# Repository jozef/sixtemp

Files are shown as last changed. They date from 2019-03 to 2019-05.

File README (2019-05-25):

NAME

    sixtemp_sensor.ino - read up to six 1-wire temperature sensors using
    Arduino and show their status using R(G)B led

SYNOPSIS

    See https://github.com/jozef/sixtemp_i2c for example and usage.

DESCRIPTION

    Arduino based sensor that can read up to six 1-wire DS18B20
    temperatures. Temperature sensors addresses are permanently stored in
    eeprom so that same positions are assigned between power-cycles. It
    provides the temperature readings via I2C interface and it also shows
    the temperature using 6xred-blue leds.

 I2C SLAVE device

    Connected to I2C, by default, responds on 0x18 address.

    First I2C master has to send one byte which is the read/write address.
    Addresses are:

        0x01        led on/off bool flag
        0x21        set led on/off flag. second byte is flag value
        0x60        read 1 byte with number of sensors
        0x61..0x66  read 14 bytes of sensor 1..6 data:
                        struct sixtemp_sensor {
                            bool has_error;
                            bool has_address;
                            int16_t tdeg;
                            char address[8];
                        };

 SERIAL INTERFACE

    Using Arduino serial port:

        $ minicom --device /dev/ttyUSB1
        eeprom magic found: 6temp 0.02

    ^^^ start-up message in case if sensors and configuration was read
    successfully from eeprom.

  help/?

    Prints version and available commands:

        > ?
        6temp 0.02
        supported commands:
          temp            - show temperatures from all sensors
          forget idx      - forget sensor on position idx
          info            - show sram usage and configuration
          set i2c [num]   - set i2c address (0x18 is default)
          tled [num]      - do led blink test num times (1 is default)
          help/?          - print this help

  info

    Prints version and debug/info:

        > info
        6temp 0.02
        sram free: 1158
        current configuration:
            i2c_addr: 0x18
            i2c_register: 0x0

  temp

    Prints all available temparature sensor readings:

        > temp
        sensor 1/6 [286164122f910528]: ERROR
        sensor 2/6 [28ff3ff6a1160322]: 22.0 C
        sensor 3/6 [286164122e7c499a]: 24.0 C
        sensor 4/6 [286164122f88f163]: 24.0 C
        sensor 5/6 [28ffa59492160558]: ERROR
        sensor 6/6 [286164122f89682a]: 24.0 C

  forget

    Forget one temperature sensor:

        > forget 1
        temp address 1 forgotten
    
        > temp
        sensor 1/6: n/a
        sensor 2/6 [28ff3ff6a1160322]: 22.0 C
        sensor 3/6 [286164122e7c499a]: 24.0 C
        sensor 4/6 [286164122f88f163]: 24.0 C
        sensor 5/6 [28ffa59492160558]: ERROR
        sensor 6/6 [286164122f89682a]: 24.0 C

  set i2c

    Change I2C client address:

        > set i2c 0x20
        setting i2c address to: 0x20
    
        > info
        6temp 0.02
        sram free: 1158
        current configuration:
            i2c_addr: 0x20
            i2c_register: 0x0
    
        > set i2c
        setting i2c address to: 0x18

  tled

    Will fade-in/out red leds and sequentially (1 to 6) blink with both
    red/blue leds to test if all are wired correctly:

        > tled 2
        testing 1/2
        fade all in/out red
        blink red
         red 1
         red 2
         red 3
         red 4
         red 5
         red 6
        LED test.
        blink blue
         blue 1
         blue 2
         blue 3
         blue 4
         blue 5
         blue 6
        testing 2/2
        ...

INSTALL

    Clone the repository folder into sketchbook/sixtemp_sensor and upload
    to Arduino.

HARDWARE

    KiCad schemas and pcb-s can be found in KiCad/ folder.

    See https://blog.kutej.net/2019/03/sixtemp for pictures of the
    hardware.

SEE ALSO

    I2C master library: https://github.com/jozef/sixtemp_i2c

TODO

        - info count&show number of errors per sensor

LICENSE

    This is free software, licensed under the MIT License.

AUTHOR

        Jozef Kutej

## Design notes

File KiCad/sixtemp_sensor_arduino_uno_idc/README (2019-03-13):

needs: https://github.com/jozef/KiCad_Arduino_Shields

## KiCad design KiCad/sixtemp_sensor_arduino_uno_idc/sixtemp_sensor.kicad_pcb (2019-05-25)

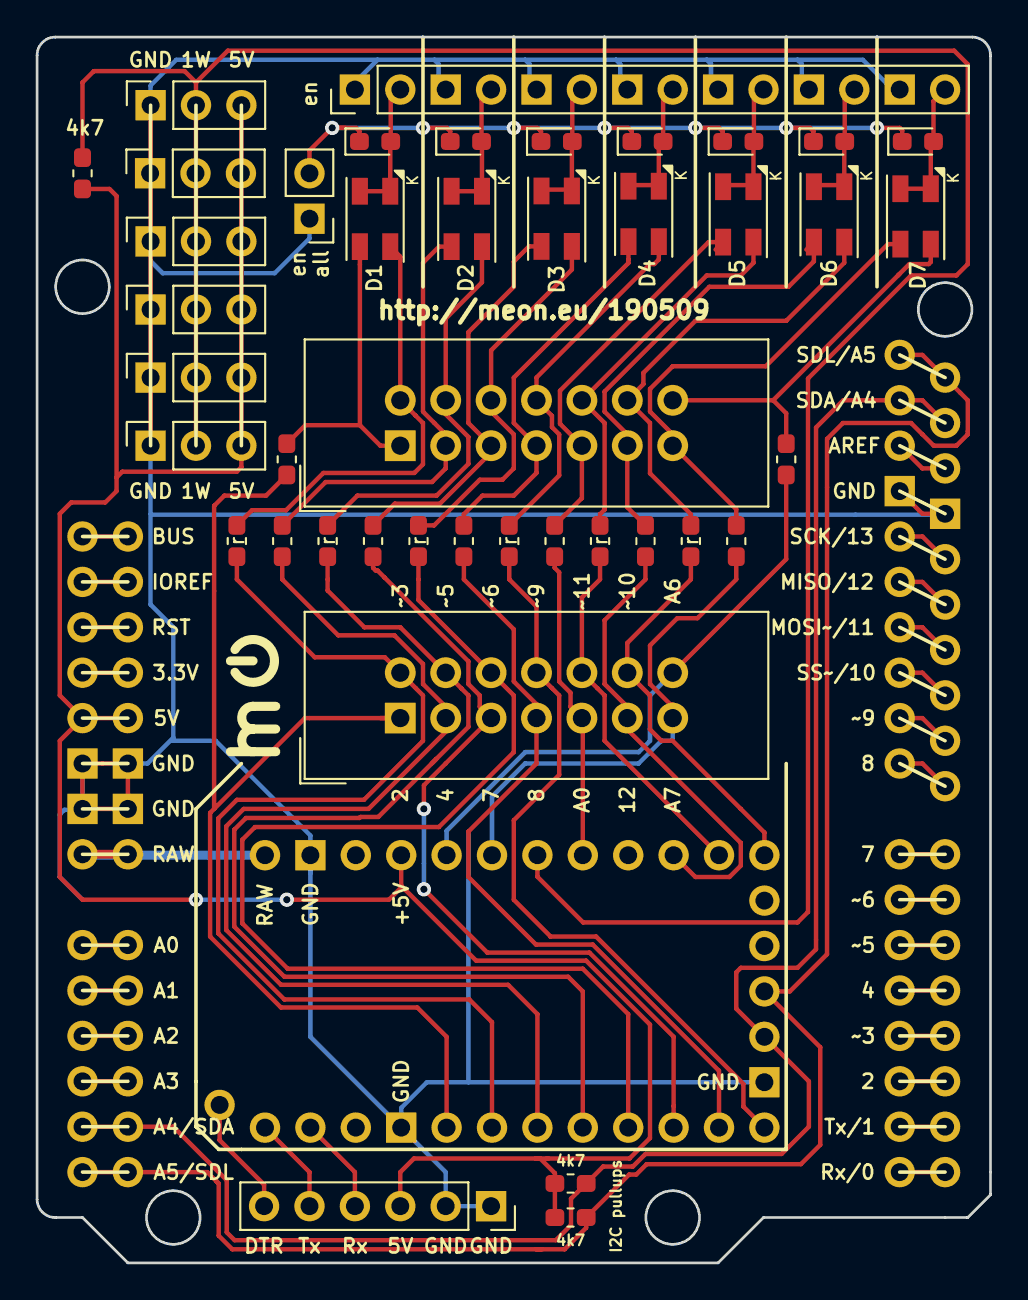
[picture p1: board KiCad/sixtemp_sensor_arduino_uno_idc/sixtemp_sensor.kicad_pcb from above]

Board: 2 copper layers, 53.3 x 68.6 mm, 44 parts (0 on the bottom side), 45 nets.

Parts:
D1, D2, D3, D4, D5, D6, D7: LED_Dual_AACC; LED_WL_SBTW_PLCC4_2.4x2.4mm_P1.7mm
D19, D29, D39, D49, D59, D69, D79: D; D_0603_1608Metric_Pad1.05x0.95mm_HandSolder
J10: debug; PinSocket_1x06_P2.54mm_Vertical
J12: Sig_conn; IDC-Header_2x07_P2.54mm_Vertical
J13: RB_Conn; IDC-Header_2x07_P2.54mm_Vertical
J31, J32, J33, J34, J35, J36: 1-Wire; PinSocket_1x03_P2.54mm_Vertical
J123456: Led_EN; PinHeader_1x14_P2.54mm_Vertical
JP99: en_all; PinHeader_1x02_P2.54mm_Vertical
R11, R12, R21, R22, R31, R32, R41, R42, R51, R52, R61, R62, R71, R72: 1k; R_0603_1608Metric_Pad1.05x0.95mm_HandSolder
R81, R82, R101: 4k7; R_0603_1608Metric_Pad1.05x0.95mm_HandSolder
U1: Arduino_Pro_Mini_12_12_5_1; Shield_Arduino_Pro_Mini_12+12+5+1_pins
U2: Arduino_Uno_Black; Arduino_Uno_Black_2rows

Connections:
1wire: J31.2, J32.2, J33.2, J34.2, J35.2, J36.2, R101.1, U1.24
10_~SS~~: J12.12, R61.2, U1.14
11_MISO~~: J12.10, R51.2, U1.15
12_MISO: J12.11, R62.2, U1.16
+5V: J10.3, J31.3, J32.3, J33.3, J34.3, J35.3, J36.3, R81.1, R82.1, R101.2, U1.4, U2.6
A0: J12.9, R52.2, U1.23
A2: J12.13, R72.2, U1.25
A3: J12.14, R71.2, U1.26
D1_Blue: D1.2, J13.1, R12.1
D1_Red: D1.1, J13.2, R11.1
D2: J12.1, R12.2, U1.32
D2_Blue: D2.2, J13.3, R22.1
D2_Red: D2.1, J13.4, R21.1
D3_Blue: D3.2, J13.5, R32.1
D3_Red: D3.1, J13.6, R31.1
D3~~: J12.2, R11.2, U1.1
D4: J12.3, R22.2, U1.2
D4_Blue: D4.2, J13.7, R42.1
D4_Red: D4.1, J13.8, R41.1
D5_Blue: D5.2, J13.9, R52.1
D5_Red: D5.1, J13.10, R51.1
D5~~: J12.4, R21.2, U1.9
D6_Blue: D6.2, J13.11, R62.1
D6_Red: D6.1, J13.12, R61.1
D6~~: J12.6, R31.2, U1.10
D7: J12.5, R32.2, U1.11
D7_Blue: D7.2, J13.13, R72.1
D7_Red: D7.1, J13.14, R71.1
D8: J12.7, R42.2, U1.12
D9~~: J12.8, R41.2, U1.13
DTR: J10.6, U1.90
EN_D1: D1.3, D1.4, D19.2, J123456.2
EN_D2: D2.3, D2.4, D29.2, J123456.4
EN_D3: D3.3, D3.4, D39.2, J123456.6
EN_D4: D4.3, D4.4, D49.2, J123456.8
EN_D5: D5.3, D5.4, D59.2, J123456.10
EN_D6: D6.3, D6.4, D69.2, J123456.12
EN_D7: D7.3, D7.4, D79.2, J123456.14
GND: J10.1, J10.2, J31.1, J32.1, J33.1, J34.1, J35.1, J36.1, J123456.1, J123456.3, J123456.5, J123456.7, J123456.9, J123456.11, J123456.13, JP99.1, U1.3, U1.5, U1.21, U2.3, U2.5, U2.21
RAW: U1.99, U2.99
Rx: J10.4, U1.30
SCL: R82.2, U1.28, U2.28
SDA: R81.2, U1.27, U2.27
Tx: J10.5, U1.31
en_all_led: D19.1, D29.1, D39.1, D49.1, D59.1, D69.1, D79.1, JP99.2

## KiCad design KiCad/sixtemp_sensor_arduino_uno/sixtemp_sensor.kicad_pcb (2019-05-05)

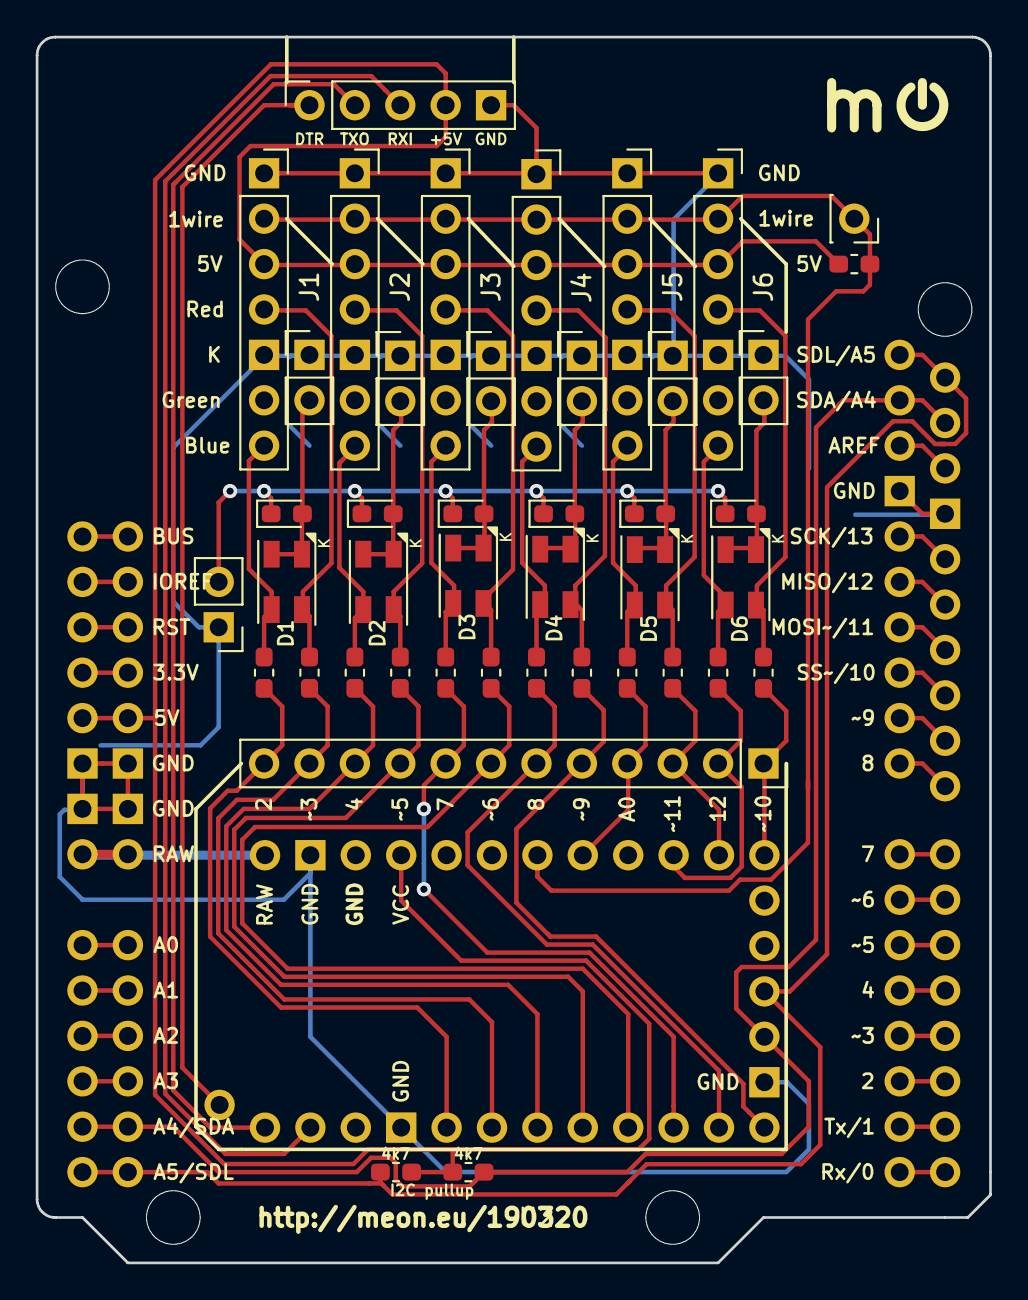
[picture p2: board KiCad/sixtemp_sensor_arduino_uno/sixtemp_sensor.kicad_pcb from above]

Board: 2 copper layers, 53.3 x 68.6 mm, 45 parts (0 on the bottom side), 40 nets.

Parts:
D1, D2, D3, D4, D5, D6: LED_Dual_AACC; LED_WL_SBTW_PLCC4_2.4x2.4mm_P1.7mm
D19, D29, D39, D49, D59, D69: D; D_0603_1608Metric_Pad1.05x0.95mm_HandSolder
J1: 1W/D_6; PinSocket_1x07_P2.54mm_Vertical
J2: 1W/D_5; PinSocket_1x07_P2.54mm_Vertical
J3: 1W/D_4; PinSocket_1x07_P2.54mm_Vertical
J4, J6: 1W/D_1; PinSocket_1x07_P2.54mm_Vertical
J5: 1W/D_2; PinSocket_1x07_P2.54mm_Vertical
J8: 1wire; PinSocket_1x01_P2.54mm_Vertical
J10: debug; PinSocket_1x05_P2.54mm_Vertical
J12: Conn_01x12_Female; PinSocket_1x12_P2.54mm_Vertical
JP1, JP2, JP3, JP4, JP5, JP6, JP99: Jumper; PinHeader_1x02_P2.54mm_Vertical
R11, R12, R21, R22, R31, R32, R41, R42, R51, R52, R61, R62: 1k; R_0603_1608Metric_Pad1.05x0.95mm_HandSolder
R81, R82, R101: 4k7; R_0603_1608Metric_Pad1.05x0.95mm_HandSolder
U1: Arduino_Pro_Mini_12_12_5_1; Shield_Arduino_Pro_Mini_12+12+5+1_pins
U2: Arduino_Uno_Black; Arduino_Uno_Black_2rows

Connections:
1wire: J1.2, J2.2, J3.2, J4.2, J5.2, J6.2, J8.1, R101.1, U1.24
10_~SS~~: J12.1, R61.2, U1.14
11_MISO~~: J12.3, R51.2, U1.15
12_MISO: J12.2, R62.2, U1.16
+5V: J1.3, J2.3, J3.3, J4.3, J5.3, J6.3, J10.4, R81.1, R82.1, R101.2, U1.4, U2.6
A0: J12.4, R52.2, U1.23
D2: J12.12, R12.2, U1.32
D3~~: J12.11, R11.2, U1.1
D4: J12.10, R22.2, U1.2
D5~~: J12.9, R21.2, U1.9
D6~~: J12.7, R31.2, U1.10
D7: J12.8, R32.2, U1.11
D8: J12.6, R42.2, U1.12
D9~~: J12.5, R41.2, U1.13
GND: J1.1, J1.5, J2.1, J2.5, J3.1, J3.5, J4.1, J4.5, J5.1, J5.5, J6.1, J6.5, J10.5, JP1.1, JP2.1, JP3.1, JP4.1, JP5.1, JP6.1, JP99.1, U1.3, U1.5, U1.21, U2.3, U2.5, U2.21
unnamed: D1.1, J1.4, R11.1
unnamed: D1.2, J1.7, R12.1
unnamed: D1.3, D1.4, D19.2, JP1.2
unnamed: D2.1, J2.4, R21.1
unnamed: D2.2, J2.7, R22.1
unnamed: D2.3, D2.4, D29.2, JP2.2
unnamed: D3.1, J3.4, R31.1
unnamed: D3.2, J3.7, R32.1
unnamed: D3.3, D3.4, D39.2, JP3.2
unnamed: D4.1, J4.4, R41.1
unnamed: D4.2, J4.7, R42.1
unnamed: D4.3, D4.4, D49.2, JP4.2
unnamed: D5.1, J5.4, R51.1
unnamed: D5.2, J5.7, R52.1
unnamed: D5.3, D5.4, D59.2, JP5.2
unnamed: D6.1, J6.4, R61.1
unnamed: D6.2, J6.7, R62.1
unnamed: D6.3, D6.4, D69.2, JP6.2
unnamed: J10.1, U1.90
unnamed: J10.2, U1.31
unnamed: J10.3, U1.30
RAW: U1.99, U2.99
SCL: R82.2, U1.28, U2.28
SDA: R81.2, U1.27, U2.27
en_all_led: D19.1, D29.1, D39.1, D49.1, D59.1, D69.1, JP99.2

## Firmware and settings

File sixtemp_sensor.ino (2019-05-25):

/*
  sixtemp_sensor.ino - read up to six 1-wire temperature sensors using Arduino
                       and show their status using R(G)B led
  (see below for documentation)
*/

#include <Arduino.h>
#include <Wire.h>
#include <OneWire.h>
#include <EEPROM.h>
#include <DallasTemperature.h>
#include <UpTime.h>             // https://github.com/jozef/Arduino-Uptime
#include "RB1WTemp.h"
#include <TextCMD.h>            // https://github.com/jozef/Arduino-TextCMD

const char MAGIC[] = "6temp 0.03";

// temperature vars
#define ONE_WIRE_BUS A1    // data one wire port A1
#define TEMPERATURE_PRECISION 12
#define MAX_SENSORS 6
const bool non_verbose = false;
const bool be_verbose = true;
const bool update_temp_leds = false;
const bool update_leds_only = true;
OneWire oneWire(ONE_WIRE_BUS);
DallasTemperature sensors(&oneWire);

#define DFT_I2C_ADDR 0x18
struct sixtemp_config {
    uint8_t i2c_addr;
    bool led_on;
    uint8_t future_conf[30];
};
uint8_t i2c_register = 0;

sixtemp_config config = {
    DFT_I2C_ADDR,    // i2c_addr
    true,            // led_on
    0,0,0,0,0,0,0,0,0,0,0,0,0,0,0,0,0,0,0,0,0,0,0,0,0,0,0,0,0,0  // place-holder for future config options
};

DeviceAddress temp_sensors[MAX_SENSORS];

#define MAX_CMD_LINE 0x1F
uint8_t current_line_end = 0;
char current_line[MAX_CMD_LINE+1];

struct ntemp_pin {
    uint8_t red;
    uint8_t blue;
};
ntemp_pin ntemp_pins[] = {
    { 3, 2 },
    { 5, 4 },
    { 6, 7 },
    { 9, 8 },
    { 11, A0 },
    { 10, 12 }
};

RB1WTemp rb1wtemps[MAX_SENSORS];

char to_send_reg0[2+sizeof(rb1wtemps[0].tdeg)+sizeof(DeviceAddress)];

#define ALARM_R_PIN A3
#define ALARM_B_PIN A2
uint8_t alarm_value = 0;

cmd_dispatch commands[] = {
    {
        "help",
        &cmd_help
    },
    {
        "?",
        &cmd_help
    },
    {
        "forget",
        &cmd_forget
    },
    {
        "cfg reset",
        &cmd_cfg_reset
    },
    {
        "temp",
        &cmd_temp
    },
    {
        "info",
        &cmd_info
    },
    {
        "set i2c",
        &cmd_set_i2c
    },
    {
        "led",
        &cmd_led
    },
    {
        "tled",
        &cmd_tled
    }
};

TextCMD cmd((sizeof(commands)/sizeof(commands[0])),commands);

const uint8_t refresh_interval = 20;
const uint8_t lookup_interval = 60;
unsigned long inactivity_ts = 0;
unsigned long next_refresh_ts = 0;
unsigned long next_lookup_ts = 0;

void setup () {
    for (uint8_t i = 0; i < MAX_SENSORS; i++) {
        rb1wtemps[i].init(ntemp_pins[i].red, ntemp_pins[i].blue,sensors);
    }

    pinMode(ALARM_R_PIN, OUTPUT);
    pinMode(ALARM_B_PIN, OUTPUT);

    Serial.begin(9600);
    while (Serial.available()) { Serial.read(); }

    char magic[strlen(MAGIC)];
    for (uint8_t i=0; i<strlen(MAGIC); i++) {
        magic[i] = EEPROM.read(i);
    }

    if (memcmp(MAGIC,magic,strlen(MAGIC)) == 0) {
        Serial.print(F("eeprom magic found: "));
        Serial.println(MAGIC);

        // read config
        for (uint8_t i = 0; i < sizeof(config); i++) {
            *((char*)&config+i) = EEPROM.read(strlen(MAGIC)+i);
        }
        // read sensors addresses
        for (uint8_t i = 0; i < MAX_SENSORS; i++) {
            uint8_t base = strlen(MAGIC)+sizeof(config)+(1+sizeof(DeviceAddress))*i;
            rb1wtemps[i].has_address = EEPROM.read(base);
            for (uint8_t si = 0; si < sizeof(DeviceAddress); si++) {
                rb1wtemps[i].address[si] = EEPROM.read(base+1+si);
            }
        }
    }
    else {
        Serial.println(F("eeprom magic missmatch, doing init"));
        // after magic, there is MAX_SENSORS of bool has_address and DeviceAddress
        // write magic
        for (uint8_t i=0; i<strlen(MAGIC); i++) {
            EEPROM.write(i,MAGIC[i]);
        }
        // write config
        for (uint8_t i = 0; i < sizeof(config); i++) {
            EEPROM.write(strlen(MAGIC)+i, *((char*)&config+i));
        }
        // zero out the rest
        for (uint8_t i=(strlen(MAGIC)+sizeof(config)); i<(strlen(MAGIC)+sizeof(config)+MAX_SENSORS+MAX_SENSORS*sizeof(DeviceAddress)); i++) {
            EEPROM.write(i,0);
        }
    }
    Serial.print(F("> "));

    Wire.begin(config.i2c_addr);
    Wire.onRequest(i2c_request);
    Wire.onReceive(i2c_receive);
}

uint8_t blink_idx = 0;
uint8_t blink_value = 1;

unsigned long tick = 0;

void loop () {
    unsigned long cur_uptime = uptime();

    // blink alarm on error
    if (no_reading_errors()) {
        digitalWrite(ALARM_R_PIN, 0);
        digitalWrite(ALARM_B_PIN, 0);
    }
    else {
        digitalWrite(ALARM_R_PIN, (alarm_value ? 1 : 0));
        digitalWrite(ALARM_B_PIN, (alarm_value ? 1 : 0));
        alarm_value = !alarm_value;
        update_temperatures(non_verbose, update_leds_only);
    }

    // re-read sensor addresses every minute
    if (next_lookup_ts < cur_uptime) {
        next_lookup_ts += lookup_interval;
        if (inactivity_ts < cur_uptime) {
            refresh_one_wire();
        }
    }
    if (next_refresh_ts < cur_uptime) {
        next_refresh_ts += refresh_interval;
        if (inactivity_ts < cur_uptime) {
            update_temperatures(non_verbose, update_temp_leds);
        }
    }

    if (inactivity_ts < cur_uptime) {
        delay(250);
    }

    while (Serial.available()) {
        static char prev_ch = 0;
        inactivity_ts = cur_uptime + 10;
        char ch = Serial.read();
        if (ch == '\b') {
            if (current_line_end) {
                Serial.print(F("\b \b"));
                current_line_end--;
                current_line[current_line_end] = '\0';
            }
        }
        else if ((ch == '\n') || (ch == '\r')) {
            if (ch == '\n' && (prev_ch == '\r')) {
                break;
            }
            Serial.println();
            if (current_line_end != 0) {
                int8_t cmd_ret = cmd.do_dispatch(current_line);
                switch (cmd_ret) {
                    case -1: Serial.println(F("unknown command or syntax error. send '?' for help")); break;
                }
                Serial.println();
            }
            Serial.print(F("> "));
            current_line[0] = '\0';
            current_line_end = 0;
        }
        else {
            if (current_line_end < MAX_CMD_LINE) {
                current_line[current_line_end++] = ch;
                current_line[current_line_end] = '\0';
                Serial.print(ch);
            }
        }
        prev_ch = ch;
    }
}

void update_temperatures(bool verbose, bool leds_only) {
    for (uint8_t i = 0; i < MAX_SENSORS; i++) {
        if (verbose) {
            Serial.print('.');
        }
        rb1wtemps[i].led_on = config.led_on;
        if (leds_only) {
            rb1wtemps[i].update_led_color(uptime());
        }
        else {
            rb1wtemps[i].refresh(uptime());
        }
    }
    if (verbose) {
        Serial.println();
    }
}

bool no_reading_errors() {
    bool one_plus_sensors = false;
    for (uint8_t i = 0; i < MAX_SENSORS; i++) {
        if (rb1wtemps[i].has_error) {
            return false;
        }
        if (rb1wtemps[i].has_address) {
            one_plus_sensors = true;
        }
    }
    if (one_plus_sensors) {
        return true;
    }
    return false;
}

void do_test_led() {
    for (uint8_t i = 0; i < MAX_SENSORS; i++) {
        rb1wtemps[i].set_red(0);
        rb1wtemps[i].set_blue(false);
    }
    digitalWrite(ALARM_R_PIN, false);
    digitalWrite(ALARM_B_PIN, false);

    Serial.println(F("fade all in/out red"));
    for (int r = 0; r < 255; r = r + 8) {
        for (uint8_t i = 0; i < MAX_SENSORS; i++) {
            rb1wtemps[i].set_red(r);
        }
        delay(30);
    }
    delay(500);
    for (int r = 255; r > 16; r = r - 8) {
        for (uint8_t i = 0; i < MAX_SENSORS; i++) {
            rb1wtemps[i].set_red(r);
        }
        delay(30);
    }
    delay(500);

    Serial.println(F("blink red"));
    for (uint8_t i = 0; i < MAX_SENSORS; i++) {
        rb1wtemps[i].set_red(255);
        Serial.print(F(" red "));
        Serial.println(i+1);
        delay(500);
        rb1wtemps[i].set_red(false);
        delay(100);
    }
    digitalWrite(ALARM_R_PIN, true);
    Serial.println(F(" red alarm"));
    delay(500);
    digitalWrite(ALARM_R_PIN, false);
    delay(500);

    Serial.println(F("LED test."));
    Serial.println(F("blink blue"));
    for (uint8_t i = 0; i < MAX_SENSORS; i++) {
        rb1wtemps[i].set_blue(true);
        Serial.print(F(" blue "));
        Serial.println(i+1);
        delay(500);
        rb1wtemps[i].set_blue(false);
        delay(100);
    }
    digitalWrite(ALARM_B_PIN, true);
    Serial.println(F(" blue alarm"));
    delay(500);
    digitalWrite(ALARM_B_PIN, false);
    delay(500);
}

void refresh_one_wire() {
    sensors.begin();
    uint8_t temp_sensors_count = sensors.getDeviceCount();
    for (uint8_t i = 0;i<temp_sensors_count;i++) {
        DeviceAddress found_sensor;
        sensors.getAddress(found_sensor,i);

        // check for known sensors and free sensor slots
        int sensor_idx = -1;
        int free_slot_idx = -1;
        for (uint8_t known_i = 0; known_i < MAX_SENSORS; known_i++) {
            if (rb1wtemps[known_i].has_address) {
                if (memcmp(rb1wtemps[known_i].address, found_sensor, sizeof(DeviceAddress)) == 0) {
                    sensor_idx = known_i;
                    break;
                }
            }
            else if (free_slot_idx == -1) {
                free_slot_idx = known_i;
            }
        }

        // save and use new found sensor
        if ((sensor_idx == -1) && (free_slot_idx != -1)) {
            Serial.print(F("new sensor found, storing at: "));
            Serial.println(free_slot_idx+1);
            Serial.println(F("> "));
            rb1wtemps[free_slot_idx].set_address(found_sensor);
            uint8_t base = strlen(MAGIC)+sizeof(config)+(1+sizeof(DeviceAddress))*free_slot_idx;
            EEPROM.write(base, 1);
            for (uint8_t si = 0; si < sizeof(DeviceAddress); si++) {
                EEPROM.write(base+si+1, rb1wtemps[free_slot_idx].address[si]);
            }
        }
    }
}

String uint8_tToString (uint8_t num) {
    if (num < 16) {
        return String("0"+String(num, HEX));
    }
    else {
        return String(num, HEX);
    }
}

int8_t cmd_forget(uint8_t argc, const char* argv[]) {
    if (argc < 2) {
        return -1;
    }
    uint8_t idx = String(argv[1]).toInt();
    if (!idx || (idx > MAX_SENSORS)) {
        Serial.print(F("failed, max sensors count is "));
        Serial.println(MAX_SENSORS);
        return 1;
    }
    rb1wtemps[idx-1].reset_address();
    uint8_t base = strlen(MAGIC)+sizeof(config)+(1+sizeof(DeviceAddress))*(idx-1);
    EEPROM.write(base, 0);
    Serial.print(F("temp address "));
    Serial.print(idx);
    Serial.println(F(" forgotten"));
    return 0;
}

int8_t cmd_tled(uint8_t argc, const char* argv[]) {
    uint8_t loops = 1;
    if (argc > 1) {
        loops = String(argv[1]).toInt();
    }
    for (uint8_t i=1; i <= loops; i++) {
        Serial.print(F("testing "));
        Serial.print(i);
        Serial.print(F("/"));
        Serial.println(loops);
        do_test_led();
    }
    return 0;
}

int8_t cmd_led(uint8_t argc, const char* argv[]) {
    if (argc < 2) {
        return -1;
    }
    if (strcmp(argv[1],"on")) {
        config.led_on = false;
    }
    else if (strcmp(argv[1],"off")) {
        config.led_on = true;
    }

    uint8_t base = strlen(MAGIC)+1;
    if (EEPROM.read(base) != config.led_on) {
        EEPROM.write(base, config.led_on);
        Serial.print(F("led set to "));
        if (config.led_on) {
            Serial.println(F("on"));
        }
        else {
            Serial.println(F("off"));
        }
    }
    return 0;
}

int8_t cmd_help(uint8_t argc, const char* argv[]) {
    Serial.println(MAGIC);
    Serial.println(F("supported commands:"));
    Serial.println(F("  temp            - show temperatures from all sensors"));
    Serial.println(F("  forget idx      - forget sensor on position idx"));
    Serial.println(F("  led on/off      - turn all led temperature indication on or off"));
    Serial.println(F("  info            - show sram usage and configuration"));
    Serial.println(F("  set i2c [num]   - set i2c address (0x18 is default)"));
    Serial.println(F("  tled [num]      - do led blink test num times (1 is default)"));
    Serial.println(F("  cfg reset       - factory reset configuration"));
    Serial.println(F("  help/?          - print this help"));
    return 0;
}

int8_t cmd_temp(uint8_t argc, const char* argv[]) {
    refresh_one_wire();
    update_temperatures(be_verbose, update_temp_leds);
    for (uint8_t i = 0; i < MAX_SENSORS; i++) {
        Serial.print(F("sensor "));
        Serial.print(i+1);
        Serial.print(F("/"));
        Serial.print(MAX_SENSORS);
        if (rb1wtemps[i].has_address) {
            Serial.print(F(" ["));
            for (uint8_t i2 = 0;i2<8;i2++) {
                Serial.print(uint8_tToString(rb1wtemps[i].address[i2]));
            }
            Serial.print(F("]: "));
            if (rb1wtemps[i].has_error) {
                Serial.println(F("ERROR"));
            }
            else {
                Serial.print(rb1wtemps[i].tdeg/10);
                Serial.print(F("."));
                Serial.print(abs(rb1wtemps[i].tdeg % 10));
                Serial.print(F(" "));
                Serial.println(F("C"));
            }
        }
        else {
            Serial.println(F(": n/a"));
        }
    }
    return 0;
}

int8_t cmd_info(uint8_t argc, const char* argv[]) {
    Serial.println(MAGIC);
    Serial.print(F("sram free: "));
    Serial.println(freeRam());
    Serial.print(F("uptime: "));
    Serial.println(uptime_as_string());
    Serial.println(F("current configuration:"));
    Serial.print(F("    i2c_addr: 0x"));
    Serial.println(String(config.i2c_addr, HEX));
    Serial.print(F("    i2c_register: 0x"));
    Serial.println(String(i2c_register, HEX));
    if (!config.led_on) {
        Serial.println(F("    led indication: off"));
    }
    return 0;
}

int8_t cmd_set_i2c(uint8_t argc, const char* argv[]) {
    uint32_t new_i2c_addr = DFT_I2C_ADDR;
    if (argc > 1) {
        if ((argv[1][0] == '0') && (argv[1][1] == 'x')) {
            new_i2c_addr = 0;
            for (uint8_t i = 2; i < strlen(argv[1]); i++) {
                new_i2c_addr = new_i2c_addr*0x10 + hex_char_to_int(argv[1][i]);
            }
        }
        else {
            new_i2c_addr = String(argv[1]).toInt();
        }
    }
    if ((new_i2c_addr < 0x0E) || (new_i2c_addr > 0x7F)) {
        Serial.print(F("i2c address 0x"));
        Serial.print(String(new_i2c_addr, HEX));
        Serial.println(F(" invalid, must be greater then 0x0E and smaller then 0x7F"));
        return 1;
    }
    Serial.print(F("setting i2c address to: 0x"));
    Serial.println(String(new_i2c_addr, HEX));
    if (config.i2c_addr != new_i2c_addr) {
        config.i2c_addr = new_i2c_addr;
        EEPROM.write(strlen(MAGIC)+0, config.i2c_addr);
        Wire.begin(config.i2c_addr);
    }
    return 0;
}

void i2c_request() {
    if (i2c_register == 0x60) {
        uint8_t count = 0;
        for (uint8_t i = 0; i < MAX_SENSORS; i++) {
            if (rb1wtemps[i].has_address) {
                count++;
            }
        }
        Wire.write(count);
    }
    else if (i2c_register == 0x01) {
        Wire.write(config.led_on);
    }
    else if ((i2c_register >= 0x60+1) && (i2c_register <= 0x60+MAX_SENSORS)) {
        uint8_t idx = i2c_register - 0x60 - 1;
        to_send_reg0[0] = rb1wtemps[idx].has_error;
        to_send_reg0[1] = rb1wtemps[idx].has_address;
        memcpy(
            &to_send_reg0[2],
            &rb1wtemps[idx].tdeg,
            sizeof(rb1wtemps[idx].tdeg)
        );
        memcpy(
            &to_send_reg0[2+sizeof(float)],
            &rb1wtemps[idx].address,
            sizeof(rb1wtemps[idx].address)
        );
        Wire.write((uint8_t*)to_send_reg0, sizeof(to_send_reg0));
    }
    else {
        Wire.write(0xff);
    }
}

void i2c_receive(int num_bytes) {
    while (num_bytes--) {
        if (i2c_register == 0x21) {
            config.led_on = Wire.read();
            i2c_register = 0x01;
            next_refresh_ts = uptime();
        }
        i2c_register = Wire.read();
    }
}

int freeRam () {
  extern int __heap_start, *__brkval;
  int v;
  return (int) &v - (__brkval == 0 ? (int) &__heap_start : (int) __brkval);
}

uint8_t hex_char_to_int(char digit_char) {
    if ((digit_char >= '0') && (digit_char <= '9')) {
        return digit_char - '0';
    }
    if ((digit_char >= 'a') && (digit_char <= 'f')) {
        return 10+(digit_char - 'a');
    }
    if ((digit_char >= 'A') && (digit_char <= 'F')) {
        return 10+(digit_char - 'A');
    }
    return 0;
}

int8_t cmd_cfg_reset(uint8_t argc, const char* argv[]) {
    EEPROM.write(0, 0);
    Serial.print(F("magic cleared, now doing reset"));
    void (*do_reset)(void) = 0;
    do_reset();
    return 0;
}

/*

=head1 NAME

sixtemp_sensor.ino - read up to six 1-wire temperature sensors using Arduino and show their status using R(G)B led

=head1 SYNOPSIS

See L<https://github.com/jozef/sixtemp_i2c> for example and usage.

=head1 DESCRIPTION

Arduino based sensor that can read up to six 1-wire DS18B20 temperatures.
Temperature sensors addresses are permanently stored in eeprom so that
same positions are assigned between power-cycles. It provides the
temperature readings via I2C interface and it also shows the temperature
using 6xred-blue leds.

=head2 I2C SLAVE device

Connected to I2C, by default, responds on 0x18 address.

First I2C master has to send one byte which is the read/write address. Addresses are:

    0x01        led on/off bool flag
    0x21        set led on/off flag. second byte is flag value
    0x60        read 1 byte with number of sensors
    0x61..0x66  read 14 bytes of sensor 1..6 data:
                    struct sixtemp_sensor {
                        bool has_error;
                        bool has_address;
                        int16_t tdeg;
                        char address[8];
                    };

=head2 SERIAL INTERFACE

Using Arduino serial port:

    $ minicom --device /dev/ttyUSB1
    eeprom magic found: 6temp 0.02

^^^ start-up message in case if sensors and configuration was read
successfully from eeprom.

=head3 help/?

Prints version and available commands:

    > ?
    6temp 0.02
    supported commands:
      temp            - show temperatures from all sensors
      forget idx      - forget sensor on position idx
      info            - show sram usage and configuration
      set i2c [num]   - set i2c address (0x18 is default)
      tled [num]      - do led blink test num times (1 is default)
      help/?          - print this help

=head3 info

Prints version and debug/info:

    > info
    6temp 0.02
    sram free: 1158
    current configuration:
        i2c_addr: 0x18
        i2c_register: 0x0

=head3 temp

Prints all available temparature sensor readings:

    > temp
    sensor 1/6 [286164122f910528]: ERROR
    sensor 2/6 [28ff3ff6a1160322]: 22.0 C
    sensor 3/6 [286164122e7c499a]: 24.0 C
    sensor 4/6 [286164122f88f163]: 24.0 C
    sensor 5/6 [28ffa59492160558]: ERROR
    sensor 6/6 [286164122f89682a]: 24.0 C

=head3 forget

Forget one temperature sensor:

    > forget 1
    temp address 1 forgotten

    > temp
    sensor 1/6: n/a
    sensor 2/6 [28ff3ff6a1160322]: 22.0 C
    sensor 3/6 [286164122e7c499a]: 24.0 C
    sensor 4/6 [286164122f88f163]: 24.0 C
    sensor 5/6 [28ffa59492160558]: ERROR
    sensor 6/6 [286164122f89682a]: 24.0 C

=head3 set i2c

Change I2C client address:

    > set i2c 0x20
    setting i2c address to: 0x20

    > info
    6temp 0.02
    sram free: 1158
    current configuration:
        i2c_addr: 0x20
        i2c_register: 0x0

    > set i2c
    setting i2c address to: 0x18

=head3 tled

Will fade-in/out red leds and sequentially (1 to 6) blink with both red/blue
leds to test if all are wired correctly:

    > tled 2
    testing 1/2
    fade all in/out red
    blink red
     red 1
     red 2
     red 3
     red 4
     red 5
     red 6
    LED test.
    blink blue
     blue 1
     blue 2
     blue 3
     blue 4
     blue 5
     blue 6
    testing 2/2
    ...

=head1 INSTALL

Clone the repository folder into F<sketchbook/sixtemp_sensor> and upload to Arduino.

=head1 HARDWARE

KiCad schemas and pcb-s can be found in F<KiCad/> folder.

See L<https://blog.kutej.net/2019/03/sixtemp> for pictures of the hardware.

=head1 SEE ALSO

I2C master library: L<https://github.com/jozef/sixtemp_i2c>


=head1 TODO

    - info count&show number of errors per sensor

=head1 LICENSE

This is free software, licensed under the MIT License.

=head1 AUTHOR

    Jozef Kutej

=cut

*/

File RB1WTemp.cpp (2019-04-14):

/* see RB1WTemp.h */

#include "RB1WTemp.h"

#define TEMPERATURE_PRECISION 12

RB1WTemp::RB1WTemp() {}

void RB1WTemp::init(uint8_t rpin, uint8_t bpin, DallasTemperature sensors) {
    _red_pin = rpin;
    _blue_pin = bpin;
    pinMode(rpin, OUTPUT);
    pinMode(bpin, OUTPUT);
    _sensors = sensors;
    reset_address();
}

void RB1WTemp::update_led_color(unsigned long tick) {
    if (!has_address) {
        has_error = false;
        digitalWrite(_red_pin, 0);
        digitalWrite(_blue_pin, 0);
        return;
    }

    if (tdeg < -1200) {
        has_error = true;
        if (tick % 5 == 0) {
            digitalWrite(_red_pin, 1);
        }
        else {
            digitalWrite(_red_pin, 0);
        }
        digitalWrite(_blue_pin, 0);
        return;
    }
    else {
        has_error = false;
    }

    // blue
    if (!led_on) {
        digitalWrite(_blue_pin, 0);
    }
    else if (tdeg < 100) {
        if (tick % 2 == 0) {
            digitalWrite(_blue_pin, 0);
        }
        else {
            digitalWrite(_blue_pin, 1);
        }
    }
    else if (tdeg < 370) {
        digitalWrite(_blue_pin, 1);
    }
    else {
        digitalWrite(_blue_pin, 0);
    }
    // red
    if (!led_on) {
        digitalWrite(_red_pin, 0);
    }
    else if (tdeg > 900) {
        if (tick % 2 == 0) {
            digitalWrite(_red_pin, 0);
        }
        else {
            digitalWrite(_red_pin, 1);
        }
    }
    else if (tdeg >= 370) {
        analogWrite(_red_pin, uint8_t((230*uint32_t(tdeg - 370))/900)+25);
    }
    else if (tdeg > 200) {
        analogWrite(_red_pin, uint8_t((255*uint32_t(tdeg - 200))/170));
    }
    else {
        digitalWrite(_red_pin, 0);
    }
}

void RB1WTemp::refresh(unsigned long tick) {
    if (has_address) {
        _sensors.requestTemperaturesByAddress(address);
        tdeg = _sensors.getTempC(address)*10;
    }
    update_led_color(tick);
}

void RB1WTemp::reset_address() {
    has_address = false;
    refresh(0);
}

void RB1WTemp::set_address(DeviceAddress new_address) {
    has_address = true;
    memcpy(address, new_address, sizeof(DeviceAddress));
    _sensors.setResolution(address, TEMPERATURE_PRECISION);
    refresh(0);
}

void RB1WTemp::set_blue(bool blue) {
    digitalWrite(_blue_pin, blue);
}

void RB1WTemp::set_red(uint8_t red) {
    analogWrite(_red_pin, red);
}

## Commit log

2017-12-29 add serial command to forget a temp sensor
2017-12-30 preparing for i2c
2017-12-30 add set i2c address
2018-01-01 provide sensor values via i2c
2018-01-03 replace String with char* to save sram
    [sixtemp_sensor.ino]
2018-01-14 show i2c register
2018-01-18 add led on/off option
2018-01-19 control config.led_on via i2c
2019-03-13 190226 version of uno shield
    [sixtemp_sensor.kicad_pcb, sixtemp_sensor.sch]
2019-03-13 adapt to 3x new pins and spacial reorganization
    [sixtemp_sensor.kicad_pcb]
2019-03-15 schematics with dtr pin and sidewise dtr/txo/rxi
    [sixtemp_sensor.kicad_pcb, sixtemp_sensor.sch]
2019-03-17 moving around pins
    [sixtemp_sensor.kicad_pcb]
2019-03-18 connector for 2x6 pins, minimize via-s
    [sixtemp_sensor.kicad_pcb, sixtemp_sensor.sch]
2019-03-19 7 pins connectors instead of 4+3
    [sixtemp_sensor.kicad_pcb, sixtemp_sensor.sch]
2019-03-19 uno with 2 rows, 1x12 header for direct pwm+digital pins, full 5 pin debug header
    [sixtemp_sensor.kicad_pcb, sixtemp_sensor.sch]
2019-03-20 revert physical order of light leds
    [sixtemp_sensor.kicad_pcb, sixtemp_sensor.sch]
2019-03-28 cfg reset cmd, refresh 1w on temp, clean-up
    [sixtemp_sensor.ino]
2019-04-14 use int16_t for temperature instead of float
2019-04-16 first idc arduino shield version
    [sixtemp_sensor.kicad_pcb, sixtemp_sensor.sch]
2019-04-24 add seventh led diode & holes to use all of the pins
    [sixtemp_sensor.kicad_pcb, sixtemp_sensor.sch]
2019-05-05 add 2x i2c pullups
    [sixtemp_sensor.kicad_pcb, sixtemp_sensor.sch]
2019-05-09 update labels, different layout
    [sixtemp_sensor.kicad_pcb, sixtemp_sensor.sch]
2019-05-23 5->6 pin debug connector
    [sixtemp_sensor.kicad_pcb, sixtemp_sensor.sch]
2019-05-23 label resistors for red led
    [sixtemp_sensor.kicad_pcb]
2019-05-24 A6→A3, A7→A2 and set as alarm
    [sixtemp_sensor.kicad_pcb, sixtemp_sensor.sch]
2019-05-25 draw lines between connected pin holes
    [sixtemp_sensor.kicad_pcb]
